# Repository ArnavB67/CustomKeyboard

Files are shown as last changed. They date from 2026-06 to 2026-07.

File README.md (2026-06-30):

# CustomKeyboard

In a month or two I am going to start with college, since I chose my major to be Electronics I wanted to get experience with making electronic projects, hence i decided to learn pcb designing and 3d modelling necessary parts. As my first electronic project i decided to make a simple custom mechanical keyboard with no rgb or bluetooth or any display, just typing.

The whole journey making this taught me how a keyboard works, how do we design a pcb,the difference between a pcb and a schematic, fundamentals for onshape 3d modelling, Initially i struggled with grid system in kicad and placing pcb switches, and making the case.

this project was a simple keyboard with only diodes switches and a raspberry pi pico, i didnt add anything like rgb,displays,bluetooth or rotatory encoder.

JournalScreenshot6
JournalScreenshot11

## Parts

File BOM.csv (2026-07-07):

Item | Quantity | Cost Per Piece | Total Cost(In Inr) | Total Cost(In Usd) | Link
1N4148 Diode | 100 | 2rs | 200 | 2.11 | https://www.amazon.in/Embeddinator-1N4148-Diode-Pack-50/dp/B0B53NV1QC
Raspberry Pi Pico | 1 | 499rs | 559(60rs delivery) | 5.9 | https://photos.app.goo.gl/vWy9ksc1XQFYdXcx7 , https://www.amazon.in/gp/product/B0B69KZBD8/ref=ox_sc_act_title_1?smid=AJ6SIZC8YQDZX&psc=1
PCB | 5 | 6480 | 6480 | 68.4 | https://photos.app.goo.gl/oPdNyKjVTfAtrtmr9
3D Printing | 1 | 2259 | 2259 | 23.84 | https://photos.app.goo.gl/7PYmRSVDV6a6SRKa9
Gateron Milky Pro Switch – 5pin | 90 | 18 | 1801(100rs delivery) | 19.01 | https://meckeys.com/shop/accessories/keyboard-accessories/key-switches/gateron-mechanical-pro-switch-5pin/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
Stabilisers(pack of 8) | 1 | 999 | 999 | 10.57 | https://meckeys.com/shop/accessories/keyboard-accessories/more/glorious-goat-stabilizers/
Total |  |  | 12298 | 129.82

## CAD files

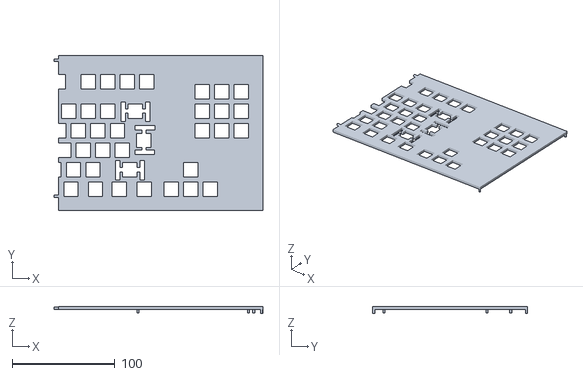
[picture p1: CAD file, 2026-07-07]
Case3DModels/KeyboardRightCase.stl
203.8 x 151.1 x 6.60

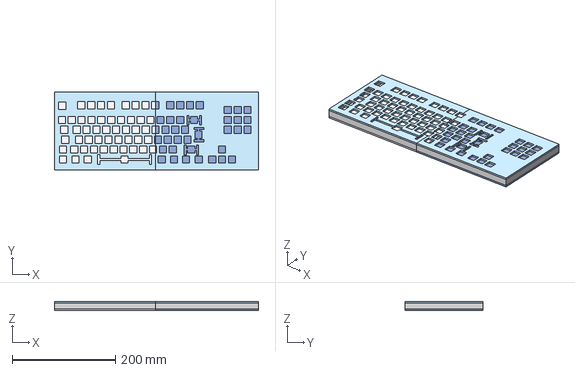
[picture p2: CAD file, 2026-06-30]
KeyboardCase.step
394.3 x 151.1 x 18.0 mm

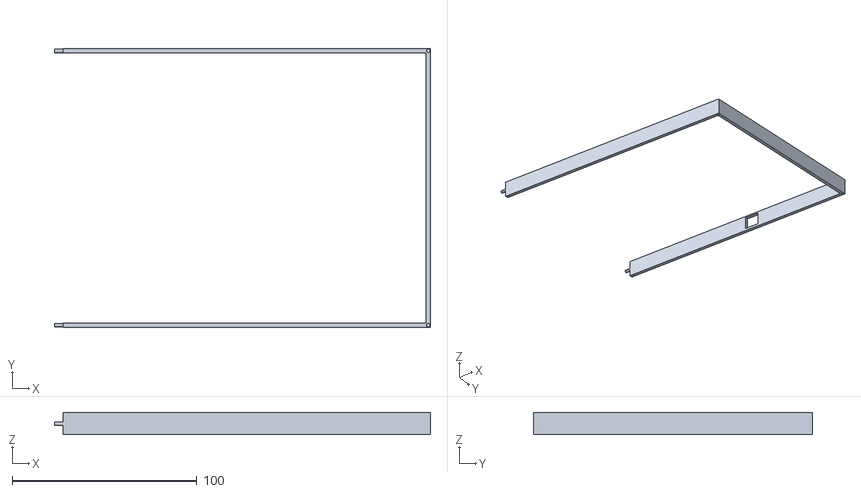
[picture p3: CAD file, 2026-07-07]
Case3DModels/KeyboardCaseMiddleRight.stl
203.8 x 151.1 x 12.0

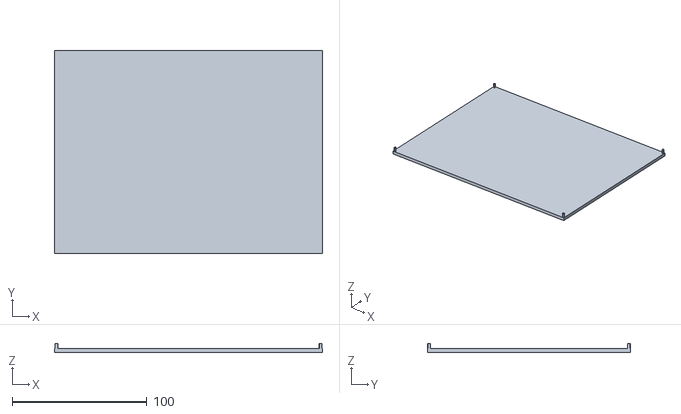
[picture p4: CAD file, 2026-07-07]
Case3DModels/KeyboardCaseBottomRight.stl
199.2 x 151.1 x 6.60

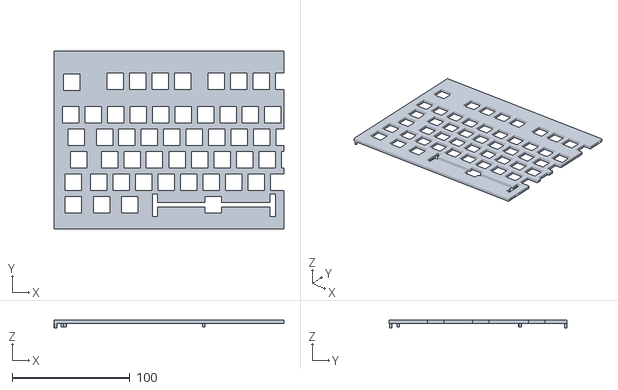
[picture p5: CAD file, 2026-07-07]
Case3DModels/KeyboardLeftCase.stl
195.2 x 151.1 x 6.60

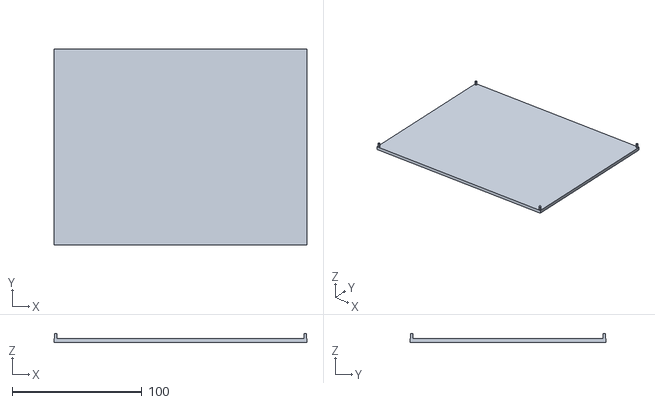
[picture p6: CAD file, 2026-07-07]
Case3DModels/KeyboardCaseBottomLeft.stl
195.2 x 151.1 x 6.60

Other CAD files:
Case3DModels/KeyboardCaseMiddleLeft.stl

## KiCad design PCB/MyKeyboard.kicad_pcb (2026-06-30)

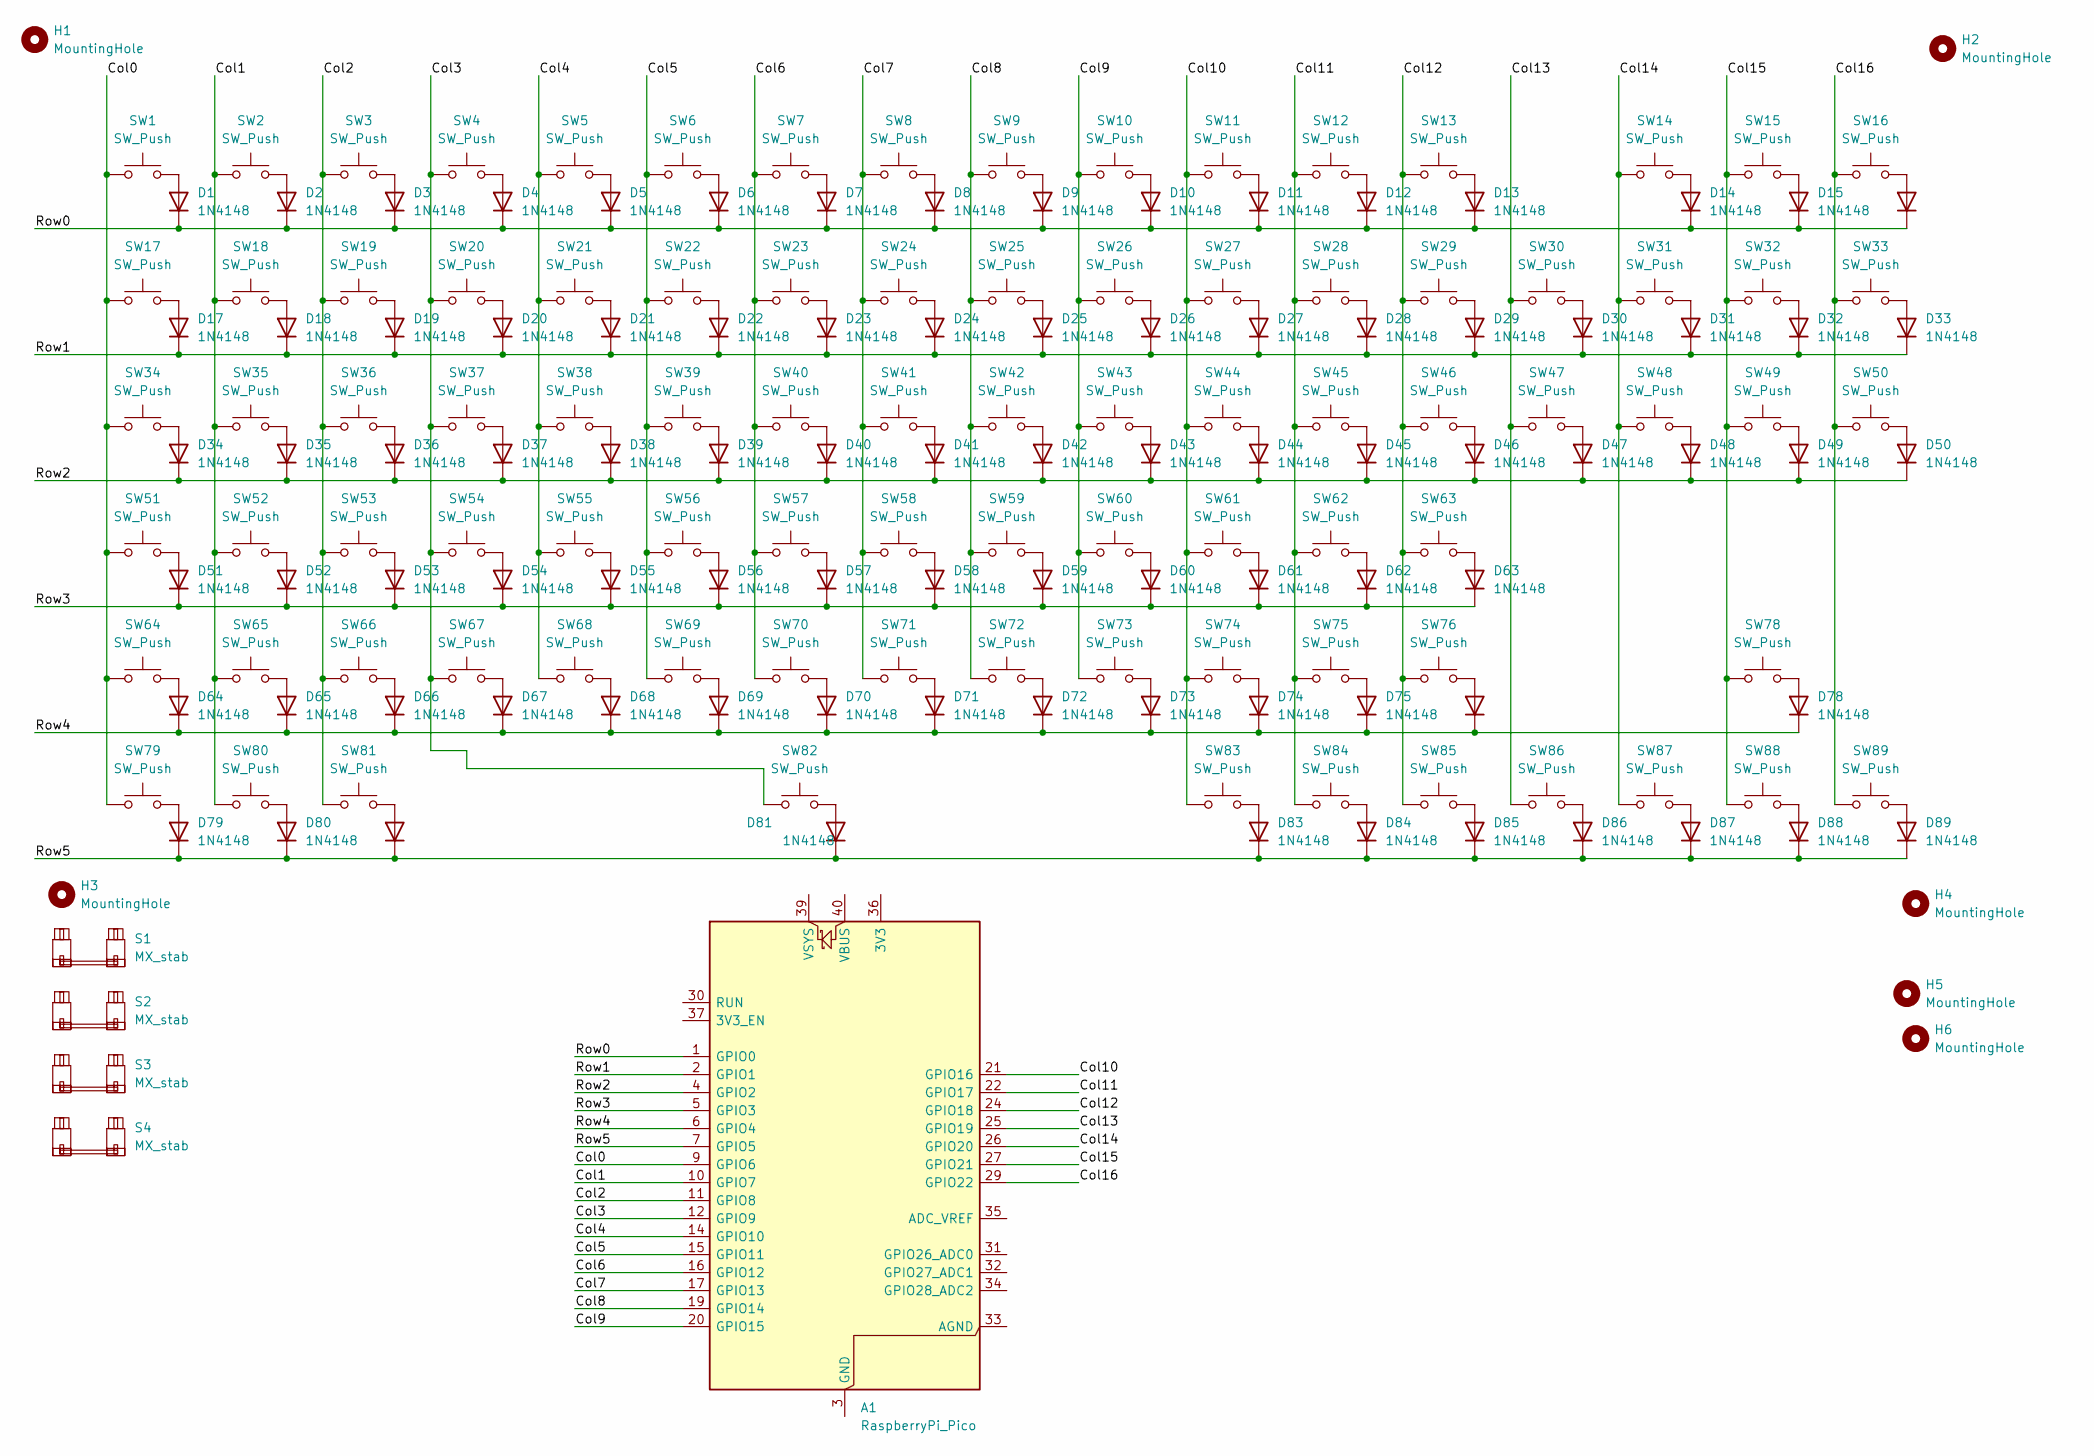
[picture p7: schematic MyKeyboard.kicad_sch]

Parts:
A1: RaspberryPi_Pico; RaspberryPi_Pico_Common_THT
D1, D2, D3, D4, D5, D6, D7, D8, D9, D10, D11, D12, D13, D14, D15, D16, D17, D18, D19, D20, D21, D22, D23, D24, D25, D26, D27, D28, D29, D30, D31, D32, D33, D34, D35, D36, D37, D38, D39, D40, D41, D42, D43, D44, D45, D46, D47, D48, D49, D50, D51, D52, D53, D54, D55, D56, D57, D58, D59, D60, D61, D62, D63, D64, D65, D66, D67, D68, D69, D70, D71, D72, D73, D74, D75, D76, D78, D79, D80, D81, D82, D83, D84, D85, D86, D87, D88, D89: 1N4148; D_DO-35_SOD27_P7.62mm_Horizontal
H1, H2, H3, H4, H5, H6: MountingHole; MountingHole_2.2mm_M2
S1: MX_stab; STAB_MX_6.25u
S2, S3: MX_stab; STAB_MX_2u
S4: MX_stab; STAB_MX_ISO
SW1, SW2, SW3, SW4, SW5, SW6, SW7, SW8, SW9, SW10, SW11, SW12, SW13, SW14, SW15, SW16, SW17, SW18, SW19, SW20, SW21, SW22, SW23, SW24, SW25, SW26, SW27, SW28, SW29, SW30, SW31, SW32, SW33, SW34, SW35, SW36, SW37, SW38, SW39, SW40, SW41, SW42, SW43, SW44, SW45, SW46, SW47, SW48, SW49, SW50, SW51, SW52, SW53, SW54, SW55, SW56, SW57, SW58, SW59, SW60, SW61, SW62, SW63, SW64, SW65, SW66, SW67, SW68, SW69, SW70, SW71, SW72, SW73, SW74, SW75, SW76, SW78, SW79, SW80, SW81, SW82, SW83, SW84, SW85, SW86, SW87, SW88, SW89: SW_Push; SW_MX_1u

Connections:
/Col0: A1.9 (GPIO6), SW1.1, SW17.1, SW34.1, SW51.1, SW64.1, SW79.1
/Col1: A1.10 (GPIO7), SW2.1, SW18.1, SW35.1, SW52.1, SW65.1, SW80.1
/Col2: A1.11 (GPIO8), SW3.1, SW19.1, SW36.1, SW53.1, SW66.1, SW81.1
/Col3: A1.12 (GPIO9), SW4.1, SW20.1, SW37.1, SW54.1, SW67.1, SW82.1
/Col4: A1.14 (GPIO10), SW5.1, SW21.1, SW38.1, SW55.1, SW68.1
/Col5: A1.15 (GPIO11), SW6.1, SW22.1, SW39.1, SW56.1, SW69.1
/Col6: A1.16 (GPIO12), SW7.1, SW23.1, SW40.1, SW57.1, SW70.1
/Col7: A1.17 (GPIO13), SW8.1, SW24.1, SW41.1, SW58.1, SW71.1
/Col8: A1.19 (GPIO14), SW9.1, SW25.1, SW42.1, SW59.1, SW72.1
/Col9: A1.20 (GPIO15), SW10.1, SW26.1, SW43.1, SW60.1, SW73.1
/Col10: A1.21 (GPIO16), SW11.1, SW27.1, SW44.1, SW61.1, SW74.1, SW83.1
/Col11: A1.22 (GPIO17), SW12.1, SW28.1, SW45.1, SW62.1, SW75.1, SW84.1
/Col12: A1.24 (GPIO18), SW13.1, SW29.1, SW46.1, SW63.1, SW76.1, SW85.1
/Col13: A1.25 (GPIO19), SW30.1, SW47.1, SW86.1
/Col14: A1.26 (GPIO20), SW14.1, SW31.1, SW48.1, SW87.1
/Col15: A1.27 (GPIO21), SW15.1, SW32.1, SW49.1, SW78.1, SW88.1
/Col16: A1.29 (GPIO22), SW16.1, SW33.1, SW50.1, SW89.1
/Row0: A1.1 (GPIO0), D1.1 (K), D2.1 (K), D3.1 (K), D4.1 (K), D5.1 (K), D6.1 (K), D7.1 (K), D8.1 (K), D9.1 (K), D10.1 (K), D11.1 (K), D12.1 (K), D13.1 (K), D14.1 (K), D15.1 (K), D16.1 (K)
/Row1: A1.2 (GPIO1), D17.1 (K), D18.1 (K), D19.1 (K), D20.1 (K), D21.1 (K), D22.1 (K), D23.1 (K), D24.1 (K), D25.1 (K), D26.1 (K), D27.1 (K), D28.1 (K), D29.1 (K), D30.1 (K), D31.1 (K), D32.1 (K), D33.1 (K)
/Row2: A1.4 (GPIO2), D34.1 (K), D35.1 (K), D36.1 (K), D37.1 (K), D38.1 (K), D39.1 (K), D40.1 (K), D41.1 (K), D42.1 (K), D43.1 (K), D44.1 (K), D45.1 (K), D46.1 (K), D47.1 (K), D48.1 (K), D49.1 (K), D50.1 (K)
/Row3: A1.5 (GPIO3), D51.1 (K), D52.1 (K), D53.1 (K), D54.1 (K), D55.1 (K), D56.1 (K), D57.1 (K), D58.1 (K), D59.1 (K), D60.1 (K), D61.1 (K), D62.1 (K), D63.1 (K)
/Row4: A1.6 (GPIO4), D64.1 (K), D65.1 (K), D66.1 (K), D67.1 (K), D68.1 (K), D69.1 (K), D70.1 (K), D71.1 (K), D72.1 (K), D73.1 (K), D74.1 (K), D75.1 (K), D76.1 (K), D78.1 (K)
/Row5: A1.7 (GPIO5), D79.1 (K), D80.1 (K), D81.1 (K), D82.1 (K), D83.1 (K), D84.1 (K), D85.1 (K), D86.1 (K), D87.1 (K), D88.1 (K), D89.1 (K)
unnamed: A1.3 (GND), A1.8 (GND), A1.13 (GND), A1.18 (GND), A1.23 (GND), A1.28 (GND), A1.38 (GND)
unnamed: D1.2 (A), SW1.2
unnamed: D2.2 (A), SW2.2
unnamed: D3.2 (A), SW3.2
unnamed: D4.2 (A), SW4.2
unnamed: D5.2 (A), SW5.2
unnamed: D6.2 (A), SW6.2
unnamed: D7.2 (A), SW7.2
unnamed: D8.2 (A), SW8.2
unnamed: D9.2 (A), SW9.2
unnamed: D10.2 (A), SW10.2
unnamed: D11.2 (A), SW11.2
unnamed: D12.2 (A), SW12.2
unnamed: D13.2 (A), SW13.2
unnamed: D14.2 (A), SW14.2
unnamed: D15.2 (A), SW15.2
unnamed: D16.2 (A), SW16.2
unnamed: D17.2 (A), SW17.2
unnamed: D18.2 (A), SW18.2
unnamed: D19.2 (A), SW19.2
unnamed: D20.2 (A), SW20.2
unnamed: D21.2 (A), SW21.2
unnamed: D22.2 (A), SW22.2
unnamed: D23.2 (A), SW23.2
unnamed: D24.2 (A), SW24.2
unnamed: D25.2 (A), SW25.2
unnamed: D26.2 (A), SW26.2
unnamed: D27.2 (A), SW27.2
unnamed: D28.2 (A), SW28.2
unnamed: D29.2 (A), SW29.2
unnamed: D30.2 (A), SW30.2
unnamed: D31.2 (A), SW31.2
unnamed: D32.2 (A), SW32.2
unnamed: D33.2 (A), SW33.2
unnamed: D34.2 (A), SW34.2
unnamed: D35.2 (A), SW35.2
unnamed: D36.2 (A), SW36.2
unnamed: D37.2 (A), SW37.2
unnamed: D38.2 (A), SW38.2
unnamed: D39.2 (A), SW39.2
unnamed: D40.2 (A), SW40.2
unnamed: D41.2 (A), SW41.2
unnamed: D42.2 (A), SW42.2
unnamed: D43.2 (A), SW43.2
unnamed: D44.2 (A), SW44.2
unnamed: D45.2 (A), SW45.2
unnamed: D46.2 (A), SW46.2
unnamed: D47.2 (A), SW47.2
unnamed: D48.2 (A), SW48.2
unnamed: D49.2 (A), SW49.2
unnamed: D50.2 (A), SW50.2
unnamed: D51.2 (A), SW51.2
unnamed: D52.2 (A), SW52.2
unnamed: D53.2 (A), SW53.2
unnamed: D54.2 (A), SW54.2
unnamed: D55.2 (A), SW55.2
unnamed: D56.2 (A), SW56.2
unnamed: D57.2 (A), SW57.2
unnamed: D58.2 (A), SW58.2
unnamed: D59.2 (A), SW59.2
unnamed: D60.2 (A), SW60.2
unnamed: D61.2 (A), SW61.2
unnamed: D62.2 (A), SW62.2
unnamed: D63.2 (A), SW63.2
unnamed: D64.2 (A), SW64.2
unnamed: D65.2 (A), SW65.2
unnamed: D66.2 (A), SW66.2
unnamed: D67.2 (A), SW67.2
unnamed: D68.2 (A), SW68.2
unnamed: D69.2 (A), SW69.2
unnamed: D70.2 (A), SW70.2
unnamed: D71.2 (A), SW71.2
unnamed: D72.2 (A), SW72.2
unnamed: D73.2 (A), SW73.2
unnamed: D74.2 (A), SW74.2
unnamed: D75.2 (A), SW75.2
unnamed: D76.2 (A), SW76.2
unnamed: D78.2 (A), SW78.2
unnamed: D79.2 (A), SW79.2
unnamed: D80.2 (A), SW80.2
unnamed: D81.2 (A), SW81.2
unnamed: D82.2 (A), SW82.2
unnamed: D83.2 (A), SW83.2
unnamed: D84.2 (A), SW84.2
unnamed: D85.2 (A), SW85.2
unnamed: D86.2 (A), SW86.2
unnamed: D87.2 (A), SW87.2
unnamed: D88.2 (A), SW88.2
unnamed: D89.2 (A), SW89.2

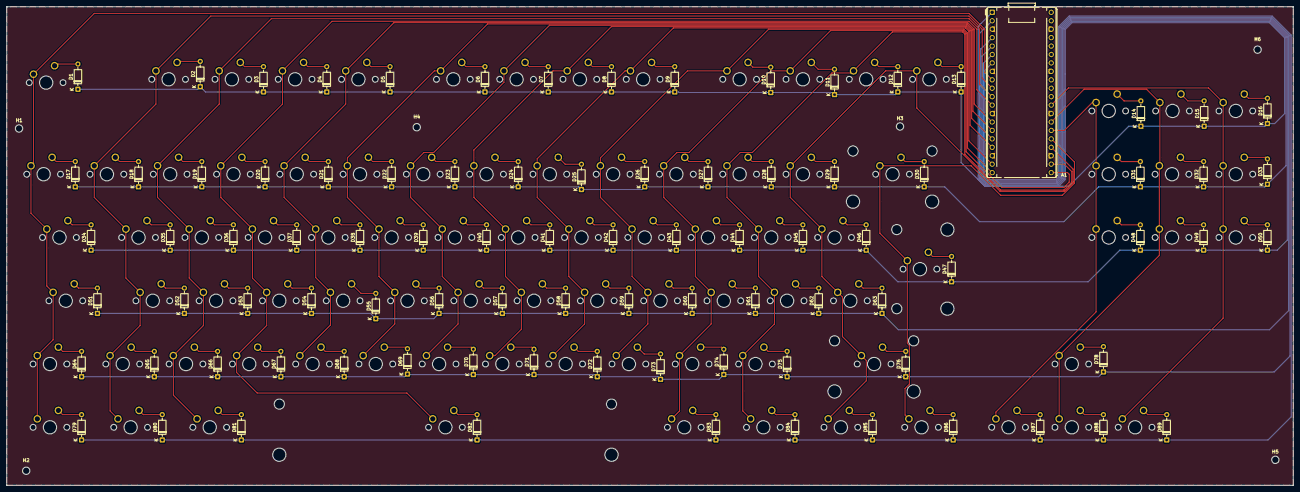
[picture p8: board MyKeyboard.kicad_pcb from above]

Board: 2 copper layers, 387.3 x 144.1 mm, 187 parts (0 on the bottom side), 112 nets.

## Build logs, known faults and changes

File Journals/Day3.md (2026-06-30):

Today I started Building the case, being unfamiliar with onshape I first became comfortable with the software by building a small bottle



Then I started the tutorial and imported my pcb step file,
I kept of following the steps provided and built a top Plate.
JournalScreenshot8

I continued and built the mid Section.

JournalScreenshot9

then I made a usb hole and the bottom layer,after that I Split the Plate.mid layer and bottom layer and added a tongue and groove joint to join everything,the 2 plates, The mid layer and the bottom layer all together.








Making this all Took me about 7 hours.
I struggled quite a  bit with making the case,since I didnt use a keyboard layout designer or a plate designer, and keys  being slightly unsymmetric for some keys i couldnt get a proper reference for key switch holes, to get the centre i  drew  2 diagonals of each square in middle of switch and marked intersection point as the centre. for the stabilisers i made a rectangle slightly larger than the big hole for pcb mount so that it could fit in.

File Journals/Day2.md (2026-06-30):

Today I Started with pcb designing, I started off with Placing the keys at their positions first,
JournalScreenshot2
JournalScreenshot3
Then I Started Placing the diodes next to the keys,
JournalScreenshot4
JournalScreenshot5
After This  was done began the final process of making the pcb that is routing the traces.
JournalScreenshot6
JournalScreenshot7

Finishing Everything took me 8 hours in total, being unfamiliar with the software I made some mistakes, I did the routing wrong initially and blocked off the route path to connect keys to the board, the keys and diodes were also sometimes not being placed correctly and were off by a few millimeters. On my first DRC run i got some missing connection errors and the pins on board were in some not allowed to place area.

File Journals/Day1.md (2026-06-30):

I started building a custom keyboard to learn more about electronics since I was interested in it and now I am going to major it  in my future studies, so to get some hand on experience with electronics I started this project to make my keyboard.

Started Off with Downloading Kicad , Setting up the Plugin and creating my first Project



After Creating my first project I  researched about what schematics are and what is difference between it and pcbs,then i decided to understand kicad basics on what the common keybinds are how to actually connect wires and all,I then Searched up how keyboard grids work and why are diodes necessary, after doing that i followed the keeb docs and completed my schematic with all connections, added stabilizers and mount holes.

JournalScreenshot1

After this I annotated my schematic and assigned footprints.

Being unfamiliar with electronics and kicad software this took me about 6hrs

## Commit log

2026-06-27 Update Day1 journal with Kicad project details
    Documented the process of creating a project in Kicad, including research on schematics, keybinds, and component placement.
2026-06-28 Add Day 2 journal entry on PCB designing
    Documented the process of PCB designing, including key placement and routing traces.
2026-06-29 Add Day 3 journal entry on case building
    Documented the progress of building the case, including steps taken and images of the work.
2026-06-30 Create PCB
